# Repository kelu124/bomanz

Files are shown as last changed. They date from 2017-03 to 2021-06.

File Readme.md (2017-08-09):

# Module: A high speed ADC for the RaspberryPi

The board in red:

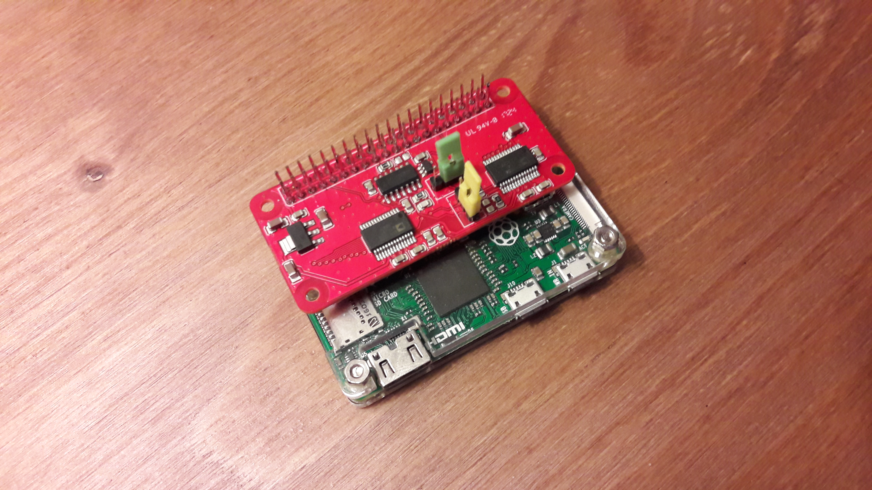
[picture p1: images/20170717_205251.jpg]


## Description

### What is it supposed to do?

I've always needed a small upgrade to the existing raspberry ADC extensions, would love something in the 20-Msps range. Let's see if one can do it! Never tried smd, and thinking of using both smd and dip.. interesting learning curve ahead.

I've tried 3 different versions, increasing in complexity

* An older version using a [CA3306](/CA3306E/) can be found as well: going around 10Msps, 6 bits. DIP based components.
* A possibly [fast version of a 8 bit AD08200 ADC](/ADC08200/) is available, going up to 12Msps. 
* The latest [24Msps pHAT](/AD9200v2/)

### Image of these HATs

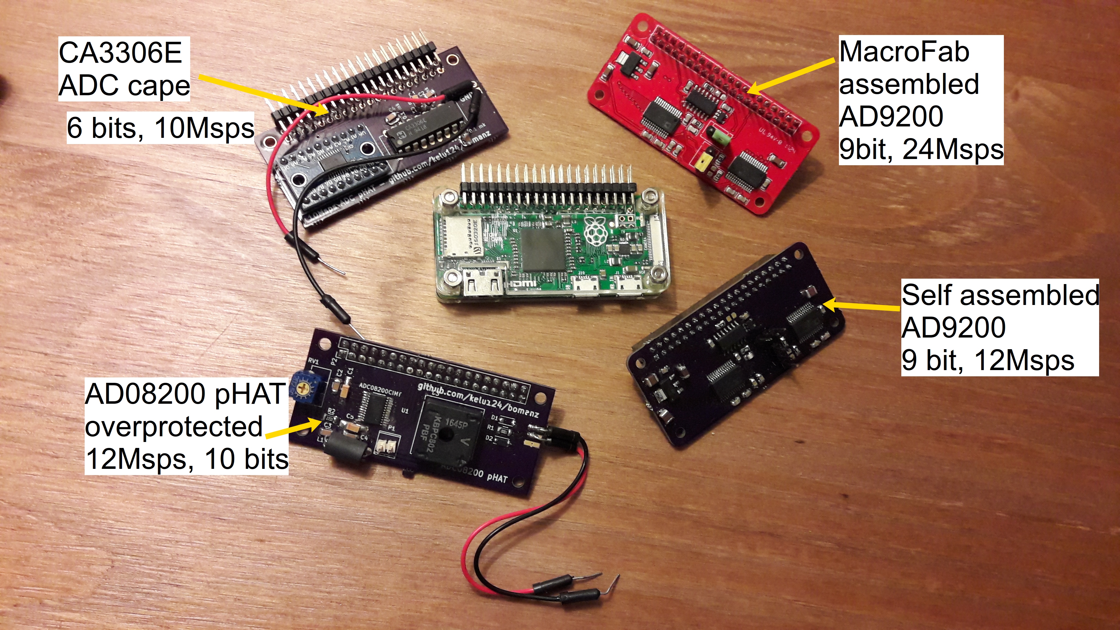
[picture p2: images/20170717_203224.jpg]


## Some results

### 24 Msps with the latest version

Details and FFT of a signal at 1.9MHz

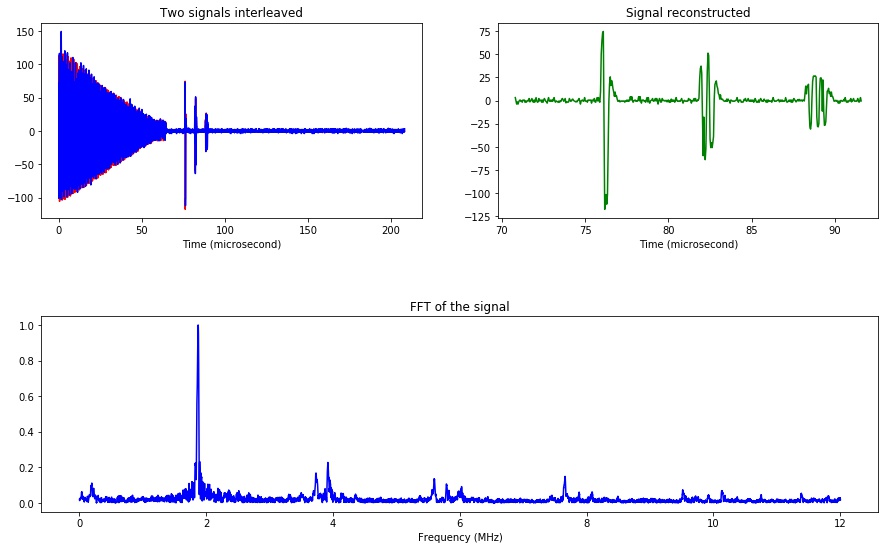
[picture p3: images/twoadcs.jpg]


### 11 Msps with the previous

FFT of a signal at 1.9MHz

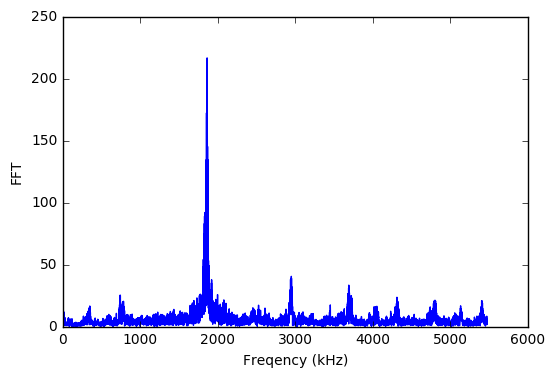
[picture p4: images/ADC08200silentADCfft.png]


### Testing a 1MHz signal with the CA3306

Imaging a 1MHz sine:

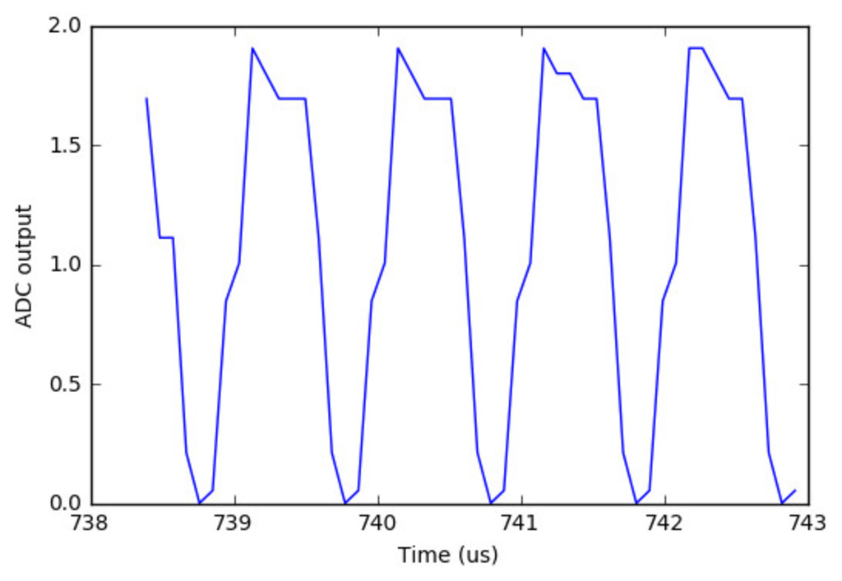
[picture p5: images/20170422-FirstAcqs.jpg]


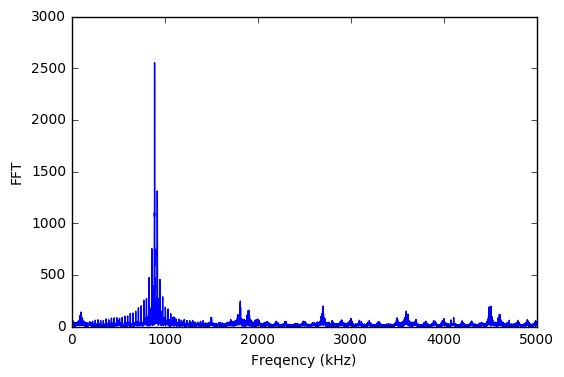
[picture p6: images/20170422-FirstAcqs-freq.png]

 
## License

### Bomanz 

The [echOmods project](https://github.com/kelu124/echomods) and its prototypes (so Bomanz) are open hardware, and working with open-hardware components.

Licensed under TAPR Open Hardware License (www.tapr.org/OHL)

Copyright Kelu124 (kelu124@gmail.com ) 2015-2018

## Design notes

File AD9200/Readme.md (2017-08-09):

# Module: Elmo pHAT [](@description Main doc source for high speed Pi DAQ)



## Name

[`MDL-DAQ_AD9200`]()

## Title

Using a dual ADC raspberry extension for 20Msps+ DAQ

## Description

* High speed ADC pHAT
* version: V1.3
* date: 10/06/2017
* cost:45$
* sourcing:OSHPark, MAcroFab
* technology: SMD, AD9200
* language: n/a
* author: Kelu124

## IOs

### Inputs

* `ITF-1_GND`
* `ITF-2_VDD_5V`
* `ITF-19_3.3V`
* `ITF-12_RPIn`

### Outputs

* `Signal Digitalized`

## Key Components

* `AD9200`

## Information

### What is it supposed to do?

The aim of this module is to achieve 10Msps, ideally 20Msps, at 9bits or more. Inspired from the [Bomanz]() project as well, which tried several high-speed ADCs setup for Raspberry Pi.

### How does it work: block diagram

Block schema

* `Raw Signal`->`ITF-12_RPIn`->`ADC`->`Buffer`->`Pi`->`Signal Digitalized`
* `ITF-4_RawSig`->`ITF-12_RPIn`
* `ITF-11_OffSig`->`ITF-12_RPIn`
* `ITF-3_ENV`->`ITF-12_RPIn`

## About the module

### Pros

* High speed, 9 bit ADCs!

### Cons

* SMDs is tough to assemble?

## Constraint and limits

* Still being debugged

### Discussions

#### Problem and solution

__Problem__ was that the Pi0 or PiW, with the current kernel module, can't run faster than around 10 to 12 Msps. Clock can be faster, but the _memcpy_ limits the transfer to memory. Soooo.. what can we do? As a reminder, I wanted at least a 10Msps 10bit ADC.

__Solution__ Why not interleaving two ADCs, with clocks in opposite phase? Hum that means 2 times 10 bits, and I had only 18 pins left once the Ultrasound SDK board connected. That means.. quite obviously, 2 times 9 bits.

So now I can run at twice the speed of the transfer, so a bit over 20Msps, over this time 9 bits. Or by oversampling, that could be 10Msps at 10 bits. __With more flexibility__ !

Win.

At least for the moment, now I need to order the PCBs and some components.

-> BOM is around 30$ components, 5$ OSHPark PCB.. that's quite neat.

#### First acquisitions:

See the [jupyter notebook](/elmo/data/20170609-NewADC-v3.ipynb):

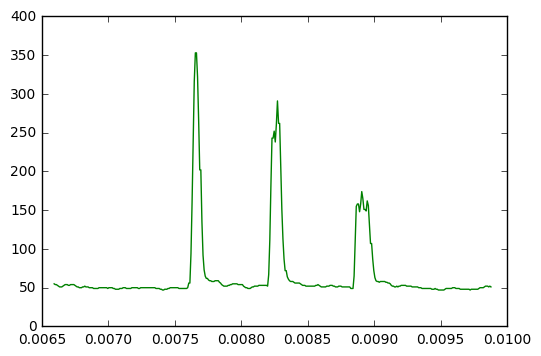
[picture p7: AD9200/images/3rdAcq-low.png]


Issues: bugs in connected ADC pins + no offset really

#### What does it look like ?

__Top in 3D__

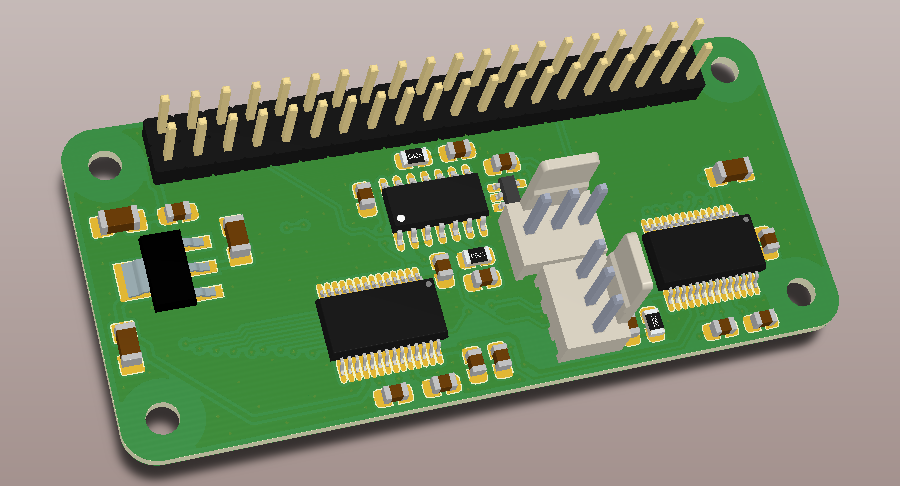
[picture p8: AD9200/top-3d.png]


__Bottom in 3D__

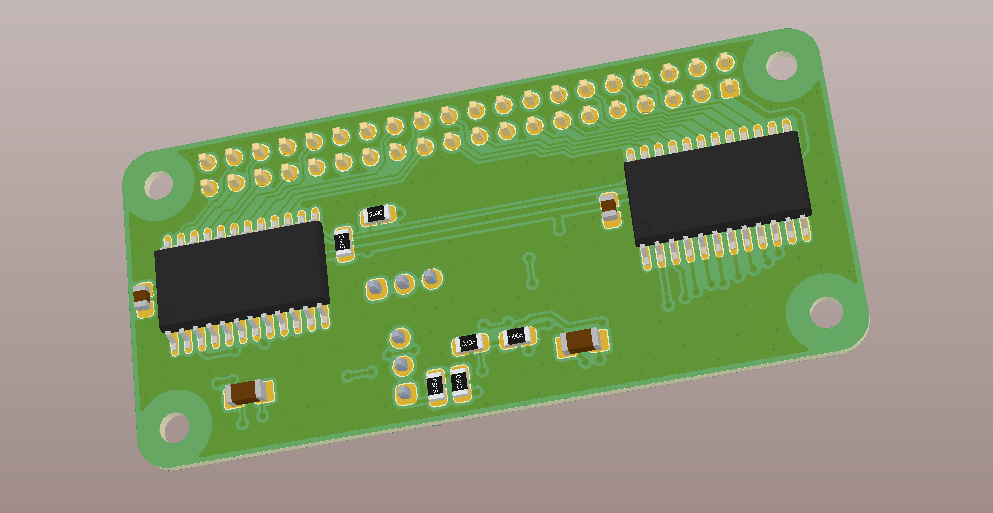
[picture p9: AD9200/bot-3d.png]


### TODO

* Lots
### DONE

* Getting a board an soldering some ADCs

### People

* @ivan for his help on altium

## License

### RetroATL3 

The [echOmods project](https://github.com/kelu124/echomods) and its prototypes (amongst which we find the [ADC pHAT](/elmo/) module) are open hardware, and working with open-hardware components.

Licensed under TAPR Open Hardware License (www.tapr.org/OHL)

Copyright Kelu124 (kelu124@gmail.com ) 2015-2018

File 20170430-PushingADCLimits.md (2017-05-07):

# 20170430 - ADC

## Objectives

1. Testing the ADC08200
2. Offseting the signal
3. Processing data and FFT'ing
4. Checking the power use of the modules at large
5. Next steps

## 1. Testing the ADC08200

Just testing if we can get the noise if we listen to the Ground

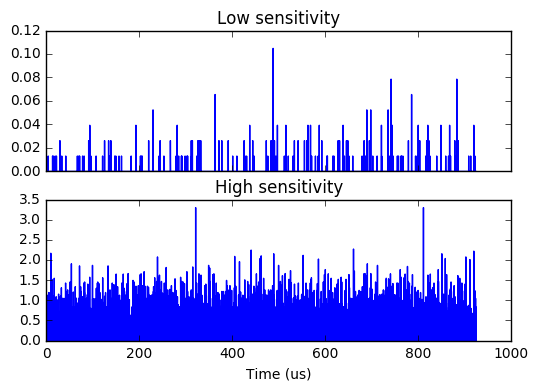
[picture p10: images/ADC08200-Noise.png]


and [getting some info/data](/ADC08200/20170430-ADC08200-FirstAcqs.ipynb)

## 2. Offsetting

The idea is to shift the signal from baseline to an average of 3.3/2V 

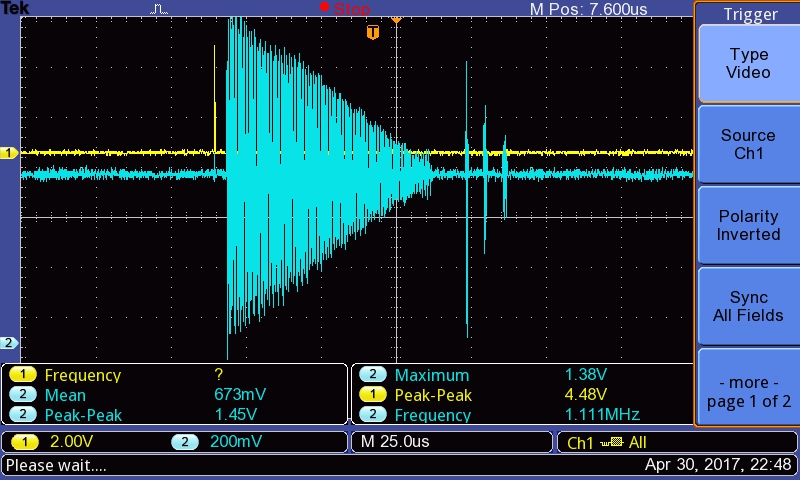
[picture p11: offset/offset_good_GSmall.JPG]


Here, it's a bit bad.

Using a __OP37G__.

## 3. Processing the data

### [First acquisitions with the ADC08200](/ADC08200/20170430-ADC08200-FirstAcqs.ipynb)

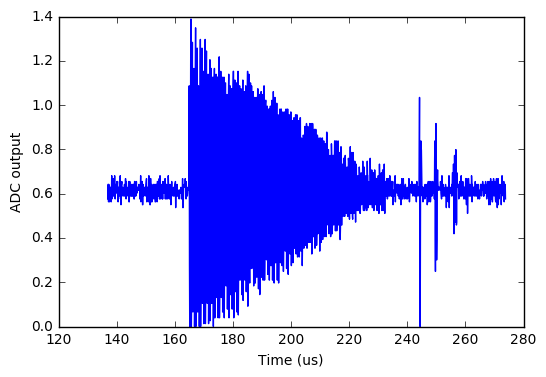
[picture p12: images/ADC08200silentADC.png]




### It should be looking like that:



### And when FFT is applied

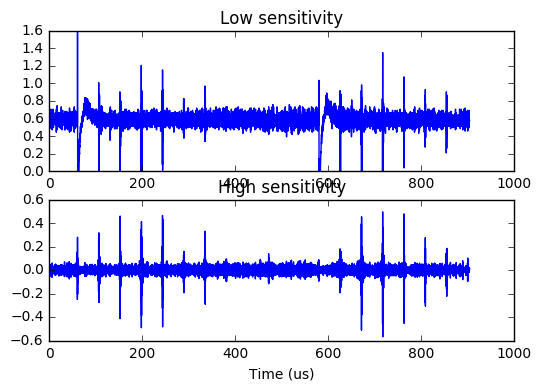
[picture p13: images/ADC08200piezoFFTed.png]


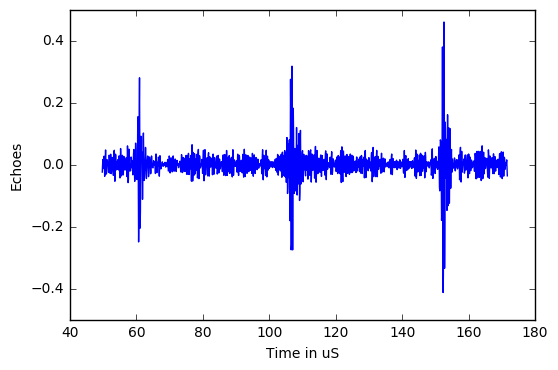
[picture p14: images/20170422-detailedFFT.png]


## 4. Checking the power use

### First stats

That's 5.1V and ...
* 273 mA with OneEye, Tobo, Goblin, Croaker, Oled
* 290 mA with OneEye, Tobo, Goblin, Croaker, Oled and the [offset module](/offset/)
* 390 mA with all of this + the raspberry

### Using with the raspberry powered outside

A simple piezo plugged onto the pulser

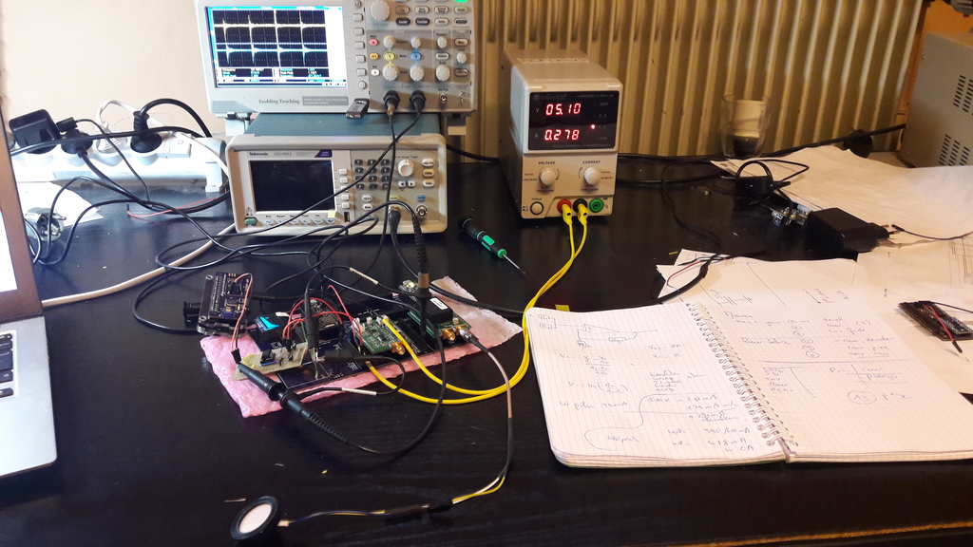
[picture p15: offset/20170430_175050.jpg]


* __Using: 5.1V et 278mA__

### Using a raspberry on the board

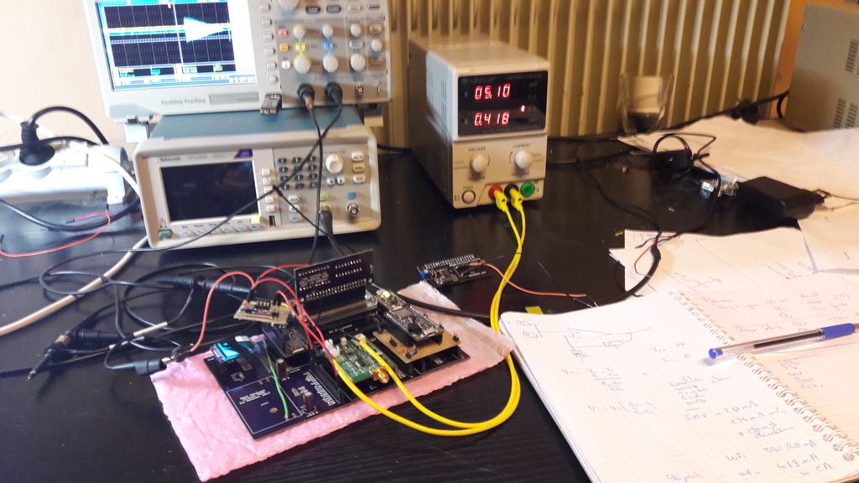
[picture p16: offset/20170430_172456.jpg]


* __Using: 5.1V et 418mA__

## 5. Next steps & challenges

__Tomorrow__
* [ ] Update the [motherboard](https://github.com/kelu124/echomods/blob/master/doj/brief_v2.md)
* [ ] Test noise on the sequence for the emulator 
* [x] Play with the VRef - [done, and not so interesting (see Notebook)](/ADC08200/20170501-TestingVref.ipynb)
* [x] Test the enveloppe detection - done, with [Hilbert and BiVi transform](/ADC08200/20170430-ADC08200-FirstAcqs.ipynb)

__Later on__
* [CANCELLED] !! Do a small PCB for the offsetter
    * Offset by 3.3V/2
    * Gain between 0.5 and 2 with a settable potentiometer 
* Check the control of the pulser by the RPi: control sequence through the ADC module
* Check if the speed of ADC acquisition can be higher

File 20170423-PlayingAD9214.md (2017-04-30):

# Alternatives

## AD9214

Drivé upstream : http://www.analog.com/media/en/technical-documentation/data-sheets/AD8475.pdf

## PRUDAQ - AD9201

The AD9201 is a complete dual channel, 20 MSPS, 10-bit
CMOS ADC used in the [PRUDAQ](http://www.cnx-software.com/2016/07/21/google-research-prudaq-is-a-40msps-adc-data-acquisition-daq-cape-for-beaglebone-black-green/)

- AD9201: 11€
- [Datasheet](/pdf/AD9201.pdf): 
 
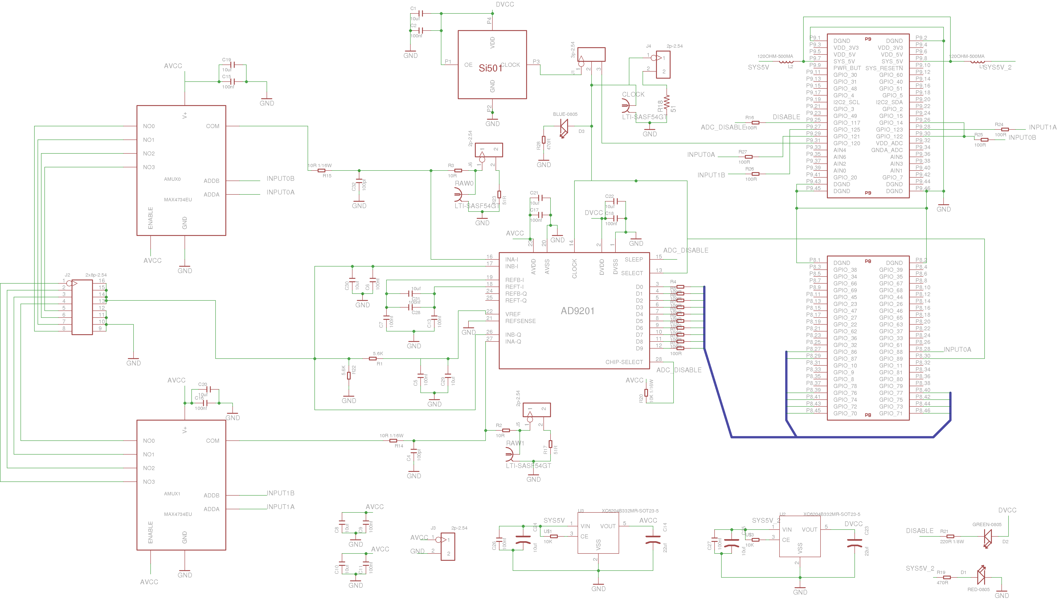
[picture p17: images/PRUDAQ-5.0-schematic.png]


## Other ?

* AD9215 for 10 bit 10-Bit, 65/80/105 MSPS
    * http://www.analog.com/en/products/analog-to-digital-converters/ad9215.html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

* AD9236 for 12 bit resolution ( http://www.analog.com/media/en/technical-documentation/data-sheets/AD9236.pdf )
* AD9245 for 14 bit resolution

* [ADC08200 for bomanz](pdf/adc08200.pdf) ... 8 bit output (1/256) 24-Lead TSSOP

## Input : low pass filter (40MHz)

* Capping

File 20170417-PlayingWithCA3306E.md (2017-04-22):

# Log file

## Intro, references, ...

Original here: https://github.com/themagpimag/magpi-issue24/tree/master/PiScope .. and with [the copy of the txt](/CA3306E/code/piscope.txt).

.. even the original ... http://paul.sullivan.za.org/raspberry-pi-oscilloscope/EE-October-1991/

See http://www.instructables.com/id/PiScope-Raspberry-Pi-based-Oscilloscope/ - inspiration for the whole project. Heart of the build:
* CA3306 (6 bit parallel A/D converter IC) -- see [datasheet](/pdf/CA3306.pdf)
* TXB0108 (logic level converter IC) 

Note to self: [Bomanz on OSHPark](https://blog.oshpark.com/2017/04/15/high-speed-adc-phat-for-raspberry-pi/), yeay!!

### Biblio

- [x] PiScope on [MagPi24](https://github.com/themagpimag/magpi-issue24/tree/master/PiScope)
- [ ] Article from [Paul Sullivan](http://paul.sullivan.za.org/raspberry-pi-oscilloscope/)
- [x] Article from [EE Oct 1991](http://paul.sullivan.za.org/raspberry-pi-oscilloscope/EE-October-1991/)
- [ ] [Instructable ref doc](http://www.instructables.com/id/PiScope-Raspberry-Pi-based-Oscilloscope/ )
- [ ] [Info on DigiBird](https://digibird1.wordpress.com/raspberry-pi-as-an-oscilloscope-10-msps/): comments on noise from the GPIOs read
- [ ] [Explainations on the kernel and macros](http://www.pieter-jan.com/node/15)
- [ ] [Better input management](http://bobdavis321.blogspot.fr/2013/06/arduino-powered-3-million-samples-per.html)
- [ ] [ARduino clocking](http://www.nutsvolts.com/magazine/article/March2014_Davis	)

## 

### Preparing the RPi

See https://www.raspberrypi.org/documentation/remote-access/ssh/passwordless.md for direct ssh

* Recommend activating Wifi, SSH, VNC beforehand
* note to self: __don't use rpi-update__ before.

### Cleaning the SD card

See this: http://raspi.tv/2016/how-to-free-up-some-space-on-your-raspbian-sd-card-remove-wolfram-libreoffice

```
sudo apt-get purge wolfram-engine wolfram-engine scratch minecraft-pi sonic-pi dillo gpicview penguinspuzzle oracle-java8-jdk openjdk-7-jre oracle-java7-jdk openjdk-8-jre chromium-browser libreoffice*
sudo apt-get remove 
sudo apt-get clean
sudo apt-get autoremove
```

If that's not enough, you can check the remaining packages by size:

```
dpkg-query -Wf '${Installed-Size}\t${Package}\n' | sort -nr | more
```

### Installing

Following the steps:

* Run the [prepareModules.sh script](/CA3306E/code/prepareModules.sh)
* Prepare the module with [ca3306.c](/CA3306E/code/ca3306.c) and the corresponding [Makefile](/CA3306E/code/Makefile) ( `ca3306-drv.c` had a couple of bugs left ) 
* Compile with:

```
sudo make
```

One can obtain details on the module via:

```
modinfo ca3306.ko
```

```
sudo insmod ./ca3306.ko
```

Check with a dmesg where the Major of the chardev with a `dmesg`. Initial source was 248, in my case 243.. check yours =)

```
sudo mknod /dev/chardev c 243 0
```

The first compilation takes a while...

### Testing 

* Test with the [getSample.cpp](/CA3306E/code/getSample.cpp)

```
g++ -o getSample getSample.cpp
./getSample > [data.txt](/CA3306E/data/1MHz.data)
```

And finally we get, for an image of a 0-2V sine at 1MHz:

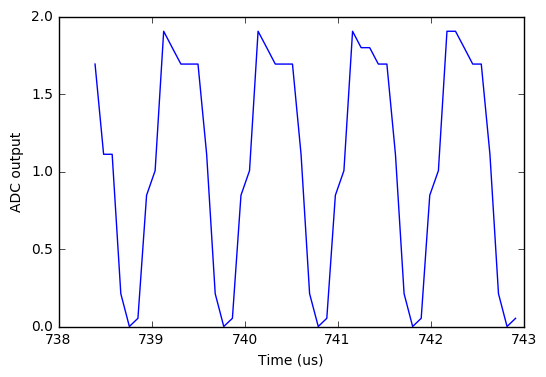
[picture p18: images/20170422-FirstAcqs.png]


Not perfect, can be better, but at least we get something that goes fast =)

### More fun ?

* See the datasheet to increase the sampling frequency with a second ADC
* See how to increase by one bit

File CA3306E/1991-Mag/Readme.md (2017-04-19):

## EE-October-1991

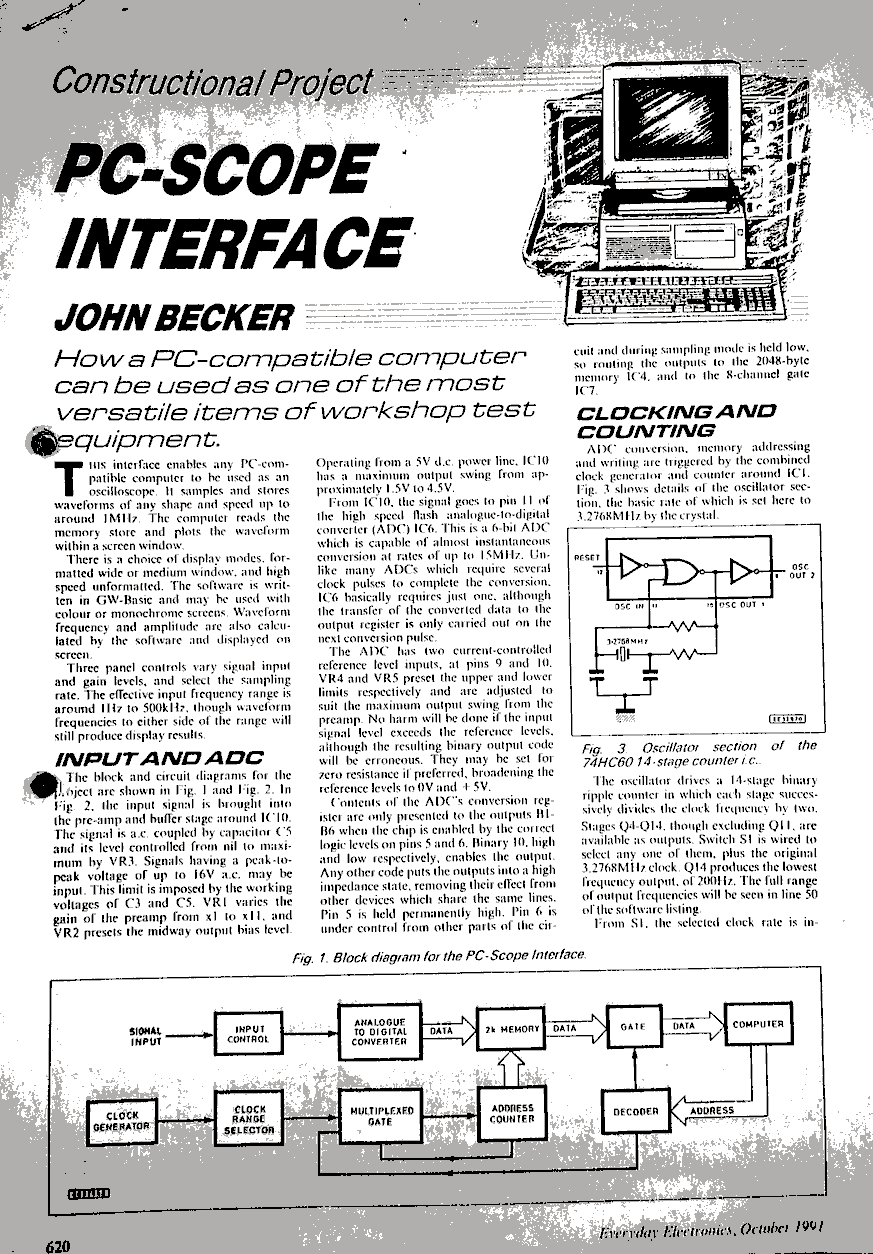
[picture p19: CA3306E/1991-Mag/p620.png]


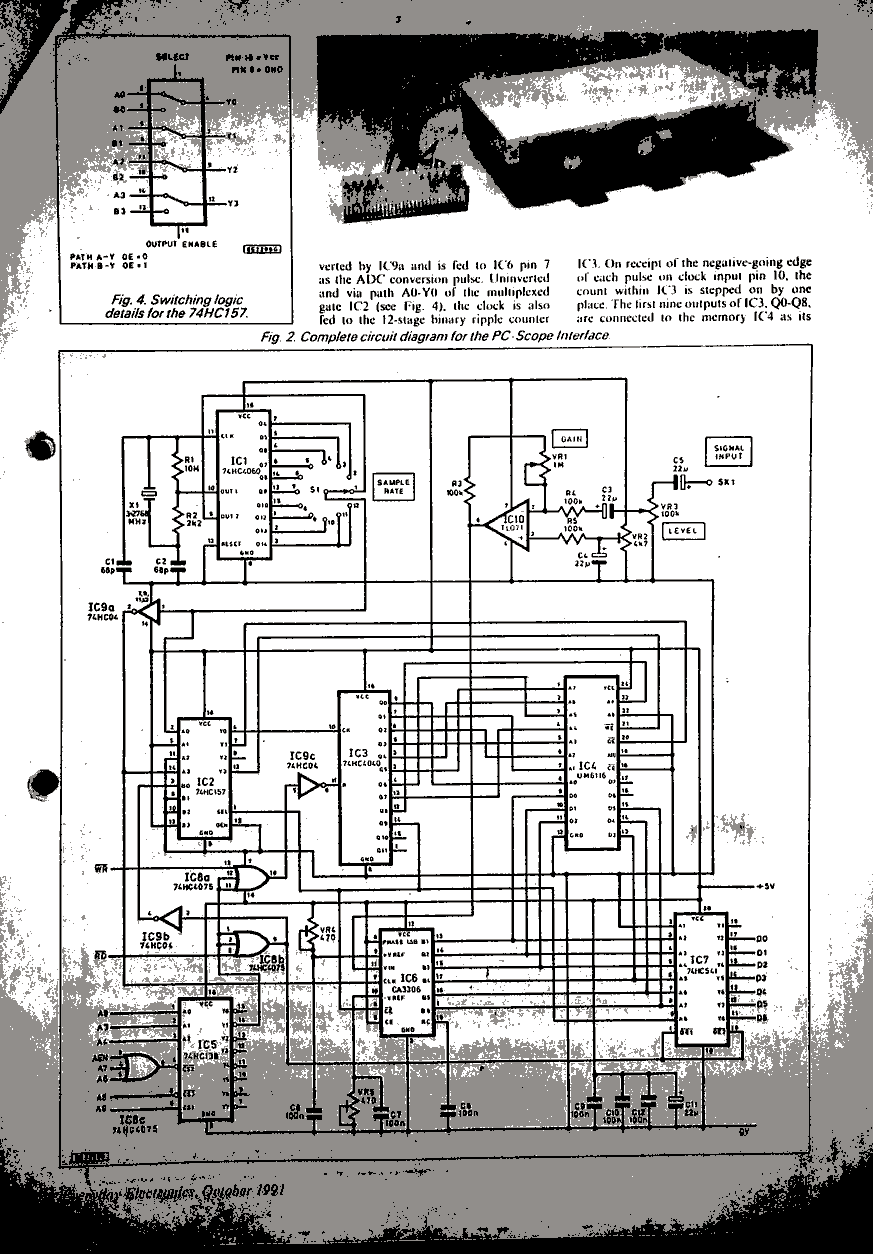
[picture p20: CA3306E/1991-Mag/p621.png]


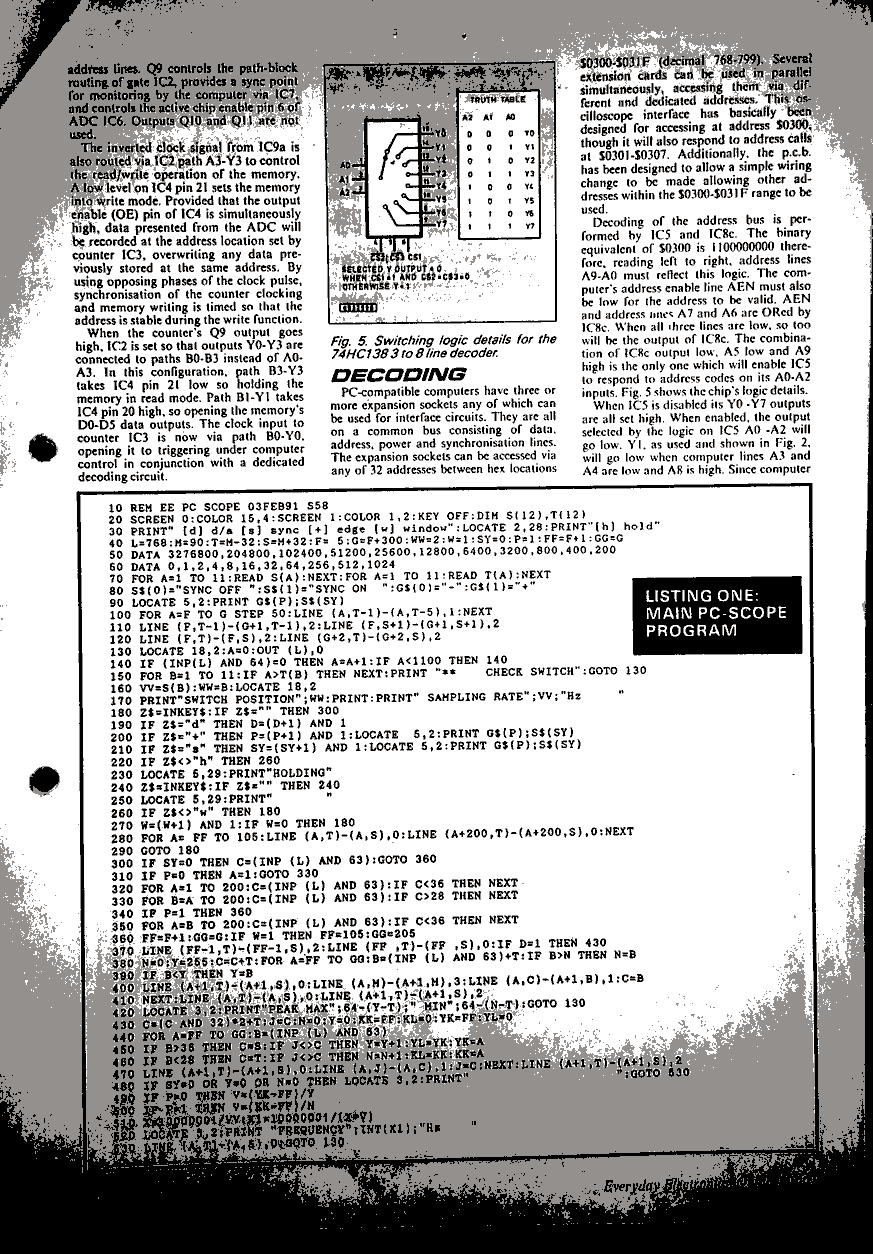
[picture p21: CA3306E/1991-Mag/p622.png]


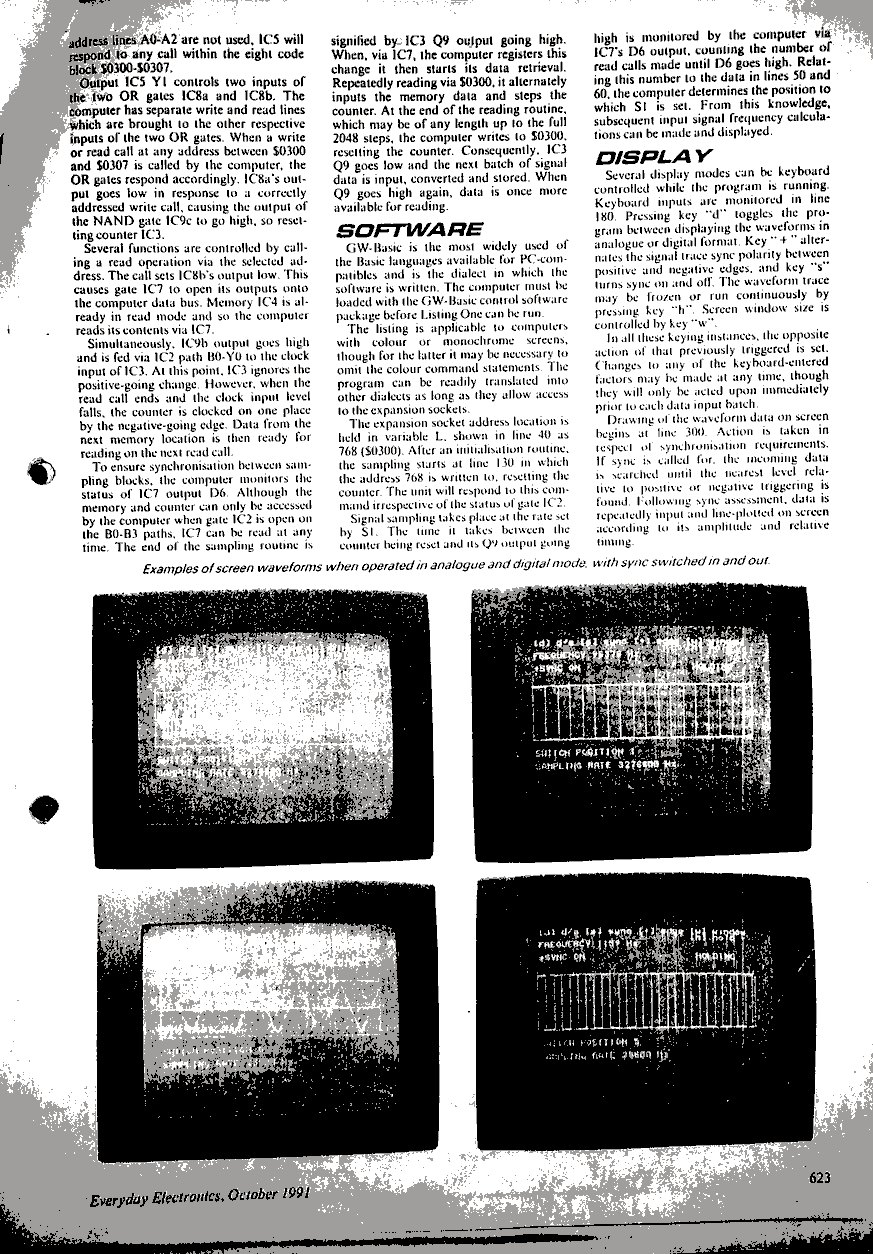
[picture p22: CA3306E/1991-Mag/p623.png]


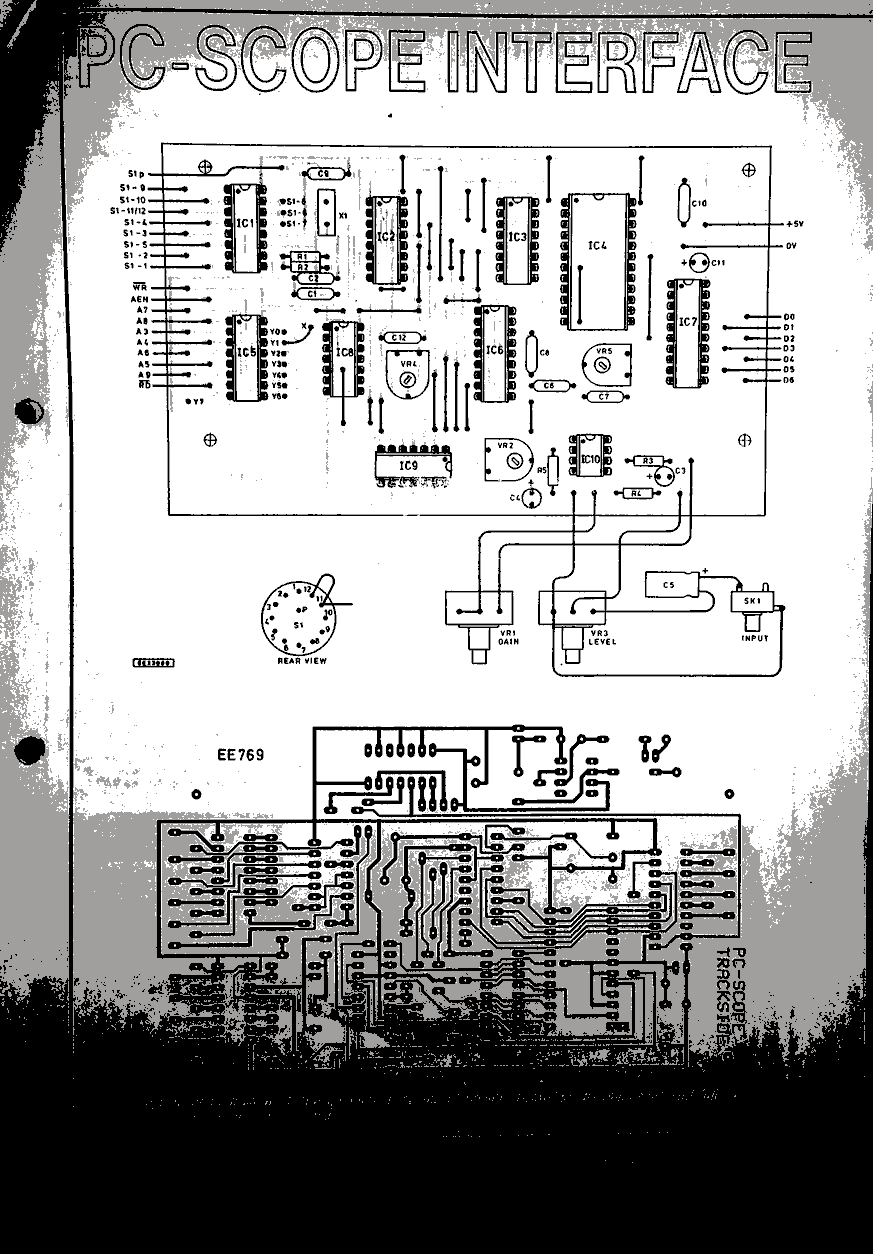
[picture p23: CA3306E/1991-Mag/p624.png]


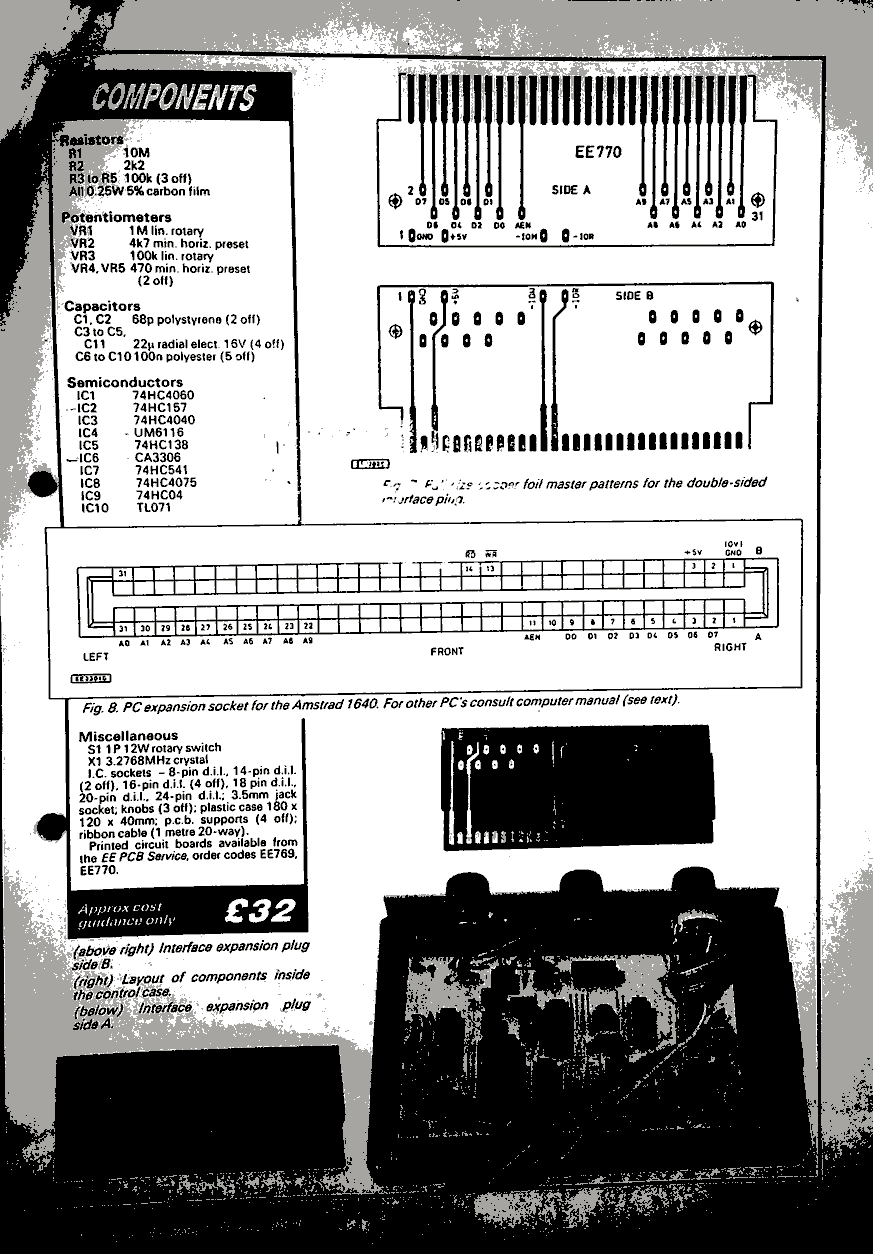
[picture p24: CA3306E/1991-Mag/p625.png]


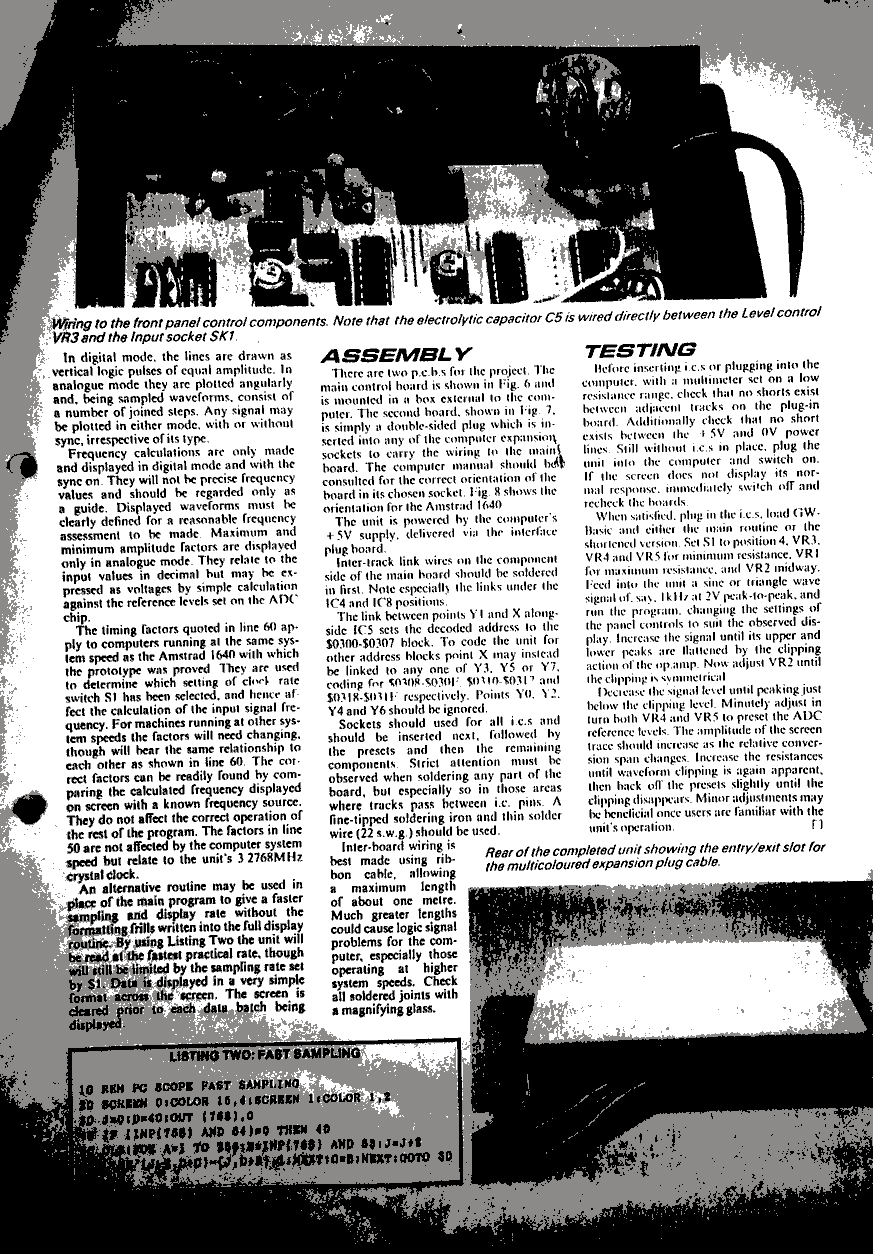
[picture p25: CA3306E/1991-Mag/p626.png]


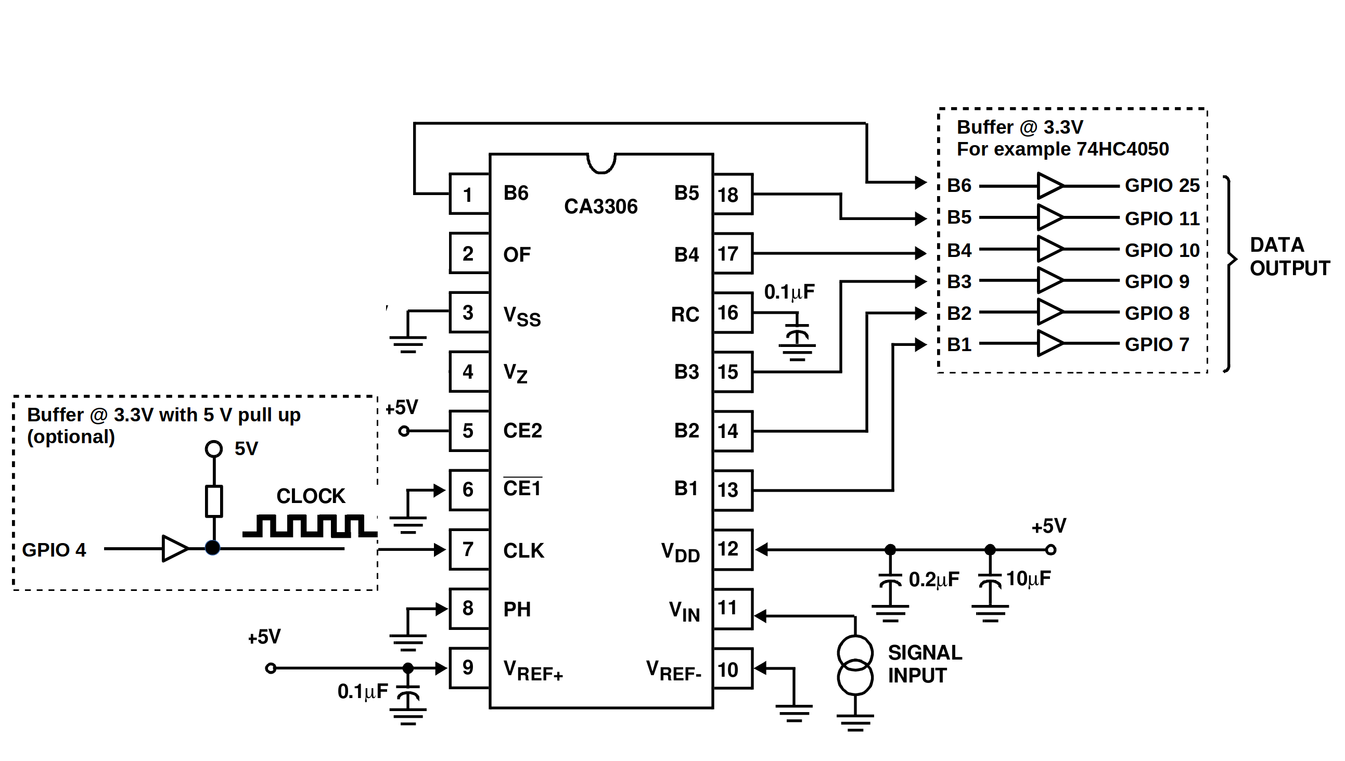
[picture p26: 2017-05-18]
images/drawing.png

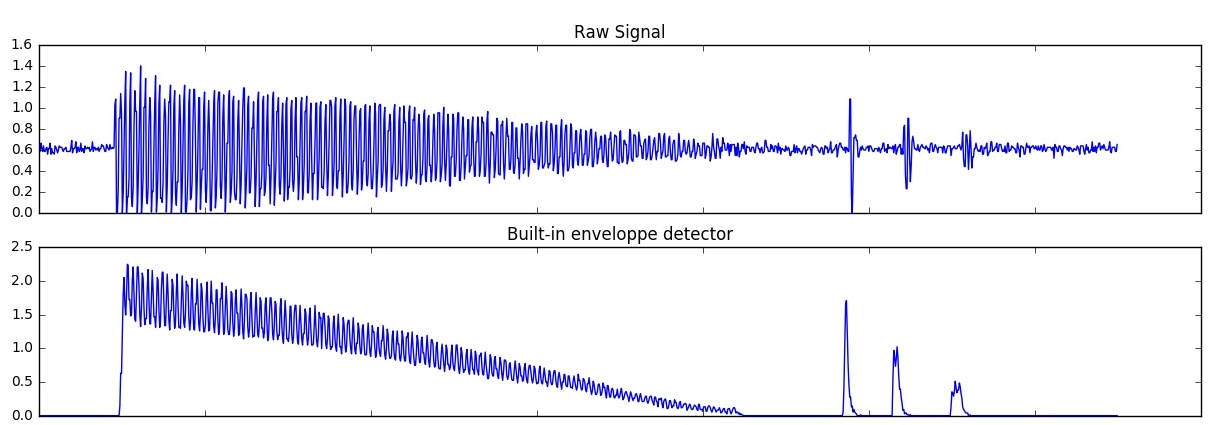
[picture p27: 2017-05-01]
images/SilentSigs.jpg

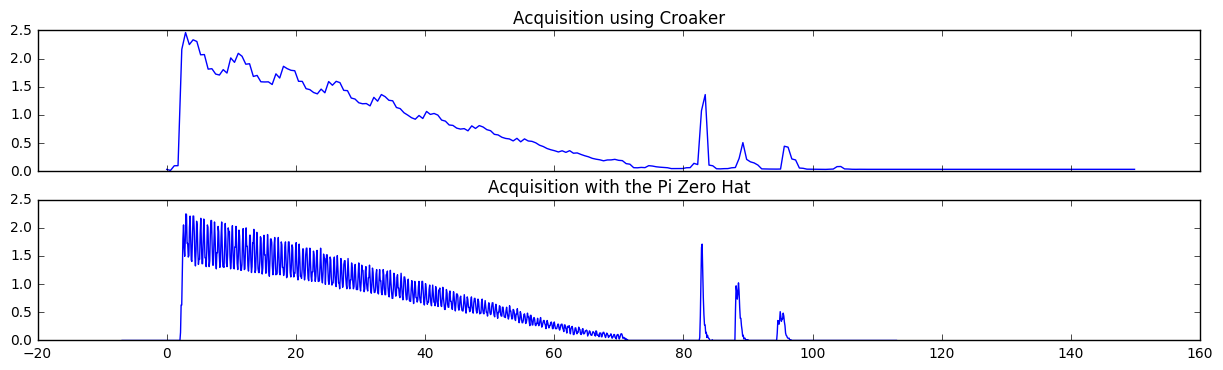
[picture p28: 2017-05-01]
images/BomanzVSCroaker.png

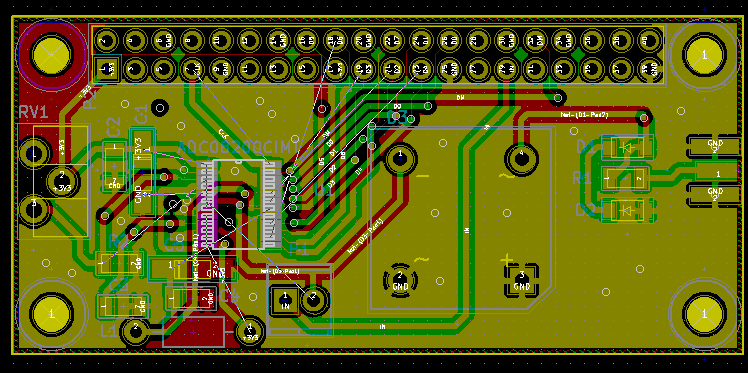
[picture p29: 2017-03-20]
images/bomanz_pcb.png

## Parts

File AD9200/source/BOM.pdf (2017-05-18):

Лист1

Страница 1

Comment | Description | Designator | Footprint | Quantity
100p | Capacitor | C1 | 0805RC | 1
10u | Capacitor | C3, C5, C6, C11, C15, C20 | 1206RC | 6
0.1u | Capacitor | C4, C7, C8, C9, C10, C12, C13, C16, C17, C19, C21, C22, C23 | 0805RC | 13
Header 20X2 | Header, 40-Pin | P1 | PLD-40 | 1
Header 3 | WF-3 etc | P2, P3 | WF-3 | 2
100 | Resistor | R1 | 0805R | 1
51 | Resistor | R2 | 0805R | 1
0 | Resistor | R4 | 0805R | 1
1k | Resistor 1% | R5, R6, R7, R8 | 0805R | 4
150 | Resistor 1% | R9, R10 | 0805R | 2
74LVC14AD | | U1 | M14A_N | 1
SN74LVC1G02DBV | | U2 | SOT-23-5L | 1
SN74LVC841ADW | 10-Bit Bus-Interface D-Type Latch with 3-State Outputs | U3, U5 | DW024_N | 2
AD9200AR | Single 10-bit ADC Parallel 20MSPS | U4, U6 | RS-28_N | 2
LD1117S33TR | Fixed Low Drop Positive Voltage Regulator, 3.3V, 4-Pin SOT-223, Tape and Reel | U7 | SOT223-4N | 1
| Hex Schmitt-Trigger Inverter, 14-Pin SOIC, Commercial Grade

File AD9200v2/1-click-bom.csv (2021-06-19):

References | Qty | Description | Manufacturer | MPN | Manufacturer | MPN | Manufacturer | MPN | Manufacturer | MPN | LCSC | Digikey | Mouser | RS | Newark | Farnell
C1 | 1 | Capacitor 100p 0805 | AVX | 08051A101J4T4A | KEMET | C0805C101J5GACTU | Samsung | CL21C101JBANNNC |  |  | C1790 | 399-1122-6-ND | 80C0805C101J5G | 2644292 |  | 1414656
C3, C5, C6, C11, C15, C20 | 6 | Capacitor 10u 1206 | AVX | TAJA106K016RNJ | Samsung | CL31A106KAHNNNE |  |  |  |  | C7171 | 1276-1075-6-ND | 581TAJA106K016R | 1360124 |  | 1432339
C4, C7, C8, C9, C10, C12, C13, C16, C17, C19, C21, C22, C23 | 13 | Capacitor 0.1u 0805 | Yageo | CC0805KRX7R9BB104 | Murata | GRM21BR71H104KA01L |  |  |  |  | C77082 | 311-1140-6-ND | 603CC805KRX7R9BB104 | 6698842 |  | 3019949
C18 | 1 | Capacitor 10n 0805 | AVX | 08051C103KAT2A | KEMET | C0805C103J5GACTU |  |  |  |  | C188188 | 478-1358-6-ND | 58108051C103K | 8029914 |  | 1535573
P2 | 1 | 3-pin general header PLS-3
P3 | 1 | 2-pin general header SCSL-2
P4 | 1 | Header, 3-Pin, Dual row Header 3X2 PBD-6
R1 | 1 | Resistor 100 0805 | Vishay | CRCW0805100RFKEA | Panasonic | ERJ-6ENF1000V | Yageo | RC0805FR-07100RL |  |  | C193990 | 311-100CRCT-ND | 603RC0805FR07100RL | 6790807 |  | 2459312
R2 | 1 | Resistor 51 0805 | Bourns | CR0805-JW-510ELF | Vishay | CRCW080551R0FKEA | TE Connectivity | CRG0805F51R | Viking Tech | CR-05FL7---51R | C416110 | A126374CT-ND | 652CR0805JW510ELF | 6791538P |  | 1469944
R4 | 1 | Resistor 0 0805 | Vishay | CRCW08050000Z0EA | Panasonic | ERJ-6GEY0R00V | Yageo | RC0805JR-070RL |  |  | C169855 | 311-0.0ARCT-ND | 603RC0805JR070RL | 6790800 |  | 1799478
R5, R6, R7, R8 | 4 | Resistor 1% 1k 0805 | Vishay | CRCW08051K00FKEA | Panasonic | ERJ-6ENF1001V | Yageo | RC0805FR-071KL |  |  | C79496 | 311-1.00KCRCT-ND | 603RC0805FR071KL | 6790982 |  | 2148706
R9, R10 | 2 | Resistor 1% 150 0805 | Bourns | CR0805-FX-1500ELF | Vishay | CRCW0805150RFKEAHP |  |  |  |  |  | CR0805-FX-1500ELFDKR-ND | 652CR0805FX1500ELF | 8123394 |  | 2908392
U1 | 1 | Hex Schmitt-Trigger Inverter, 14-Pin SOIC, Commercial Grade 74LVC14AD M14A_N | Rochester Electronics | 74LVC14AD |  | 74LVC14AD
U2 | 1 | SN74LVC1G02DBV SOT-23-5L | Texas Instruments | SN74LVC1G02DBV |  | SN74LVC1G02DBV
U3, U5 | 2 | 10-Bit Bus-Interface D-Type Latch with 3-State Outputs SN74LVC841ADW DW024_N | Texas Instruments | SN74LVC841ADW |  | SN74LVC841ADW |  |  |  |  |  | 296-8552-5-ND | 595SN74LVC841ADW |  |  | 1741602
U4, U6 | 2 | Single 10-bit ADC Parallel 20MSPS AD9200AR RS-28_N | Analog Devices | AD9200ARS |  |  |  |  |  |  |  |  | 584AD9200ARS
U7 | 1 | Fixed Low Drop Positive Voltage Regulator, 3.3V, 4-Pin SOT-223, Tape and Reel LD1117S33TR SOT223-4N | STMicroelectronics | LD1117S33TR |  | LD1117S33TR |  |  |  |  | C86781 | 497-1242-1-ND | 511LD1117S33 | 7140697 |  | 2393623

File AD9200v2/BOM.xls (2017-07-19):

Comment | Description | Designator | Footprint | Quantity
100p | Capacitor | C1 | 0805RC | 1
10u | Capacitor | C3, C5, C6, C11, C15, C20 | 1206RC | 6
0.1u | Capacitor | C4, C7, C8, C9, C10, C12, C13, C16, C17, C19, C21, C22, C23 | 0805RC | 13
10n | Capacitor | C18 | 0805RC | 1
PLS-3 | 3-pin general header | P2 | PLS-3 | 1
Header 2 | 2-pin general header | P3 | SCSL-2 | 1
Header 3X2 | Header, 3-Pin, Dual row | P4 | PBD-6 | 1
100 | Resistor | R1 | 0805R | 1
51 | Resistor | R2 | 0805R | 1
0 | Resistor | R4 | 0805R | 1
1k | Resistor 1% | R5, R6, R7, R8 | 0805R | 4
150 | Resistor 1% | R9, R10 | 0805R | 2
74LVC14AD | Hex Schmitt-Trigger Inverter, 14-Pin SOIC, Commercial Grade | U1 | M14A_N | 1
SN74LVC1G02DBV |  | U2 | SOT-23-5L | 1
SN74LVC841ADW | 10-Bit Bus-Interface D-Type Latch with 3-State Outputs | U3, U5 | DW024_N | 2
AD9200AR | Single 10-bit ADC Parallel 20MSPS | U4, U6 | RS-28_N | 2
LD1117S33TR | Fixed Low Drop Positive Voltage Regulator, 3.3V, 4-Pin SOT-223, Tape and Reel | U7 | SOT223-4N | 1

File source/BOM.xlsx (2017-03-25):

Sr. No. | Designator | Description | Package | Quantity | URL | Part No.
1 | P2 | Pin Header Straight 2x20 Pitch2.54mm | 2x20 DIP 2.54 mm Pitch | 1 | http://www.digikey.com/product-detail/en/ amphenol-fci/10046971-003LF/609-2859-ND/1589877 | 10046971-003LF
2 | U1 | ADC08200 24 Pin | TSSOP | 1 | http://www.digikey.com/product-detail/ en/texas-instruments/ADC08200CIMT-NOPB/ADC08200CIMT-NOPB-ND/482880 (http://www.digikey.com/product-detail/en/texas-instruments/ADC08200CIMT-NOPB/ADC08200CIMT-NOPB-ND/482880) | ADC08200CIMT/NOPB-ND
3 | C1,C5 | Capacitor Tantalum 10uF | 1206 | 2 | http://www.digikey.com/products/ en?keywords=399-3684-2-ND (http://www.digikey.com/products/en?keywords=399-3684-2-ND) | 399-3684-2-ND
4 | C2,C3,C4 | Capacitor 0.1uF | 1206 | 3 | http://www.digikey.com/products /en?keywords=399-1249-2-ND (http://www.digikey.com/products/en?keywords=399-1249-2-ND) | 399-1249-2-ND
5 | D1,D2 | Zener Diode | SOD-123 | 2 | http://www.digikey.com/products /en?keywords=mmsz5221b-fditr-nd (http://www.digikey.com/products/en?keywords=mmsz5221b-fditr-nd) | MMSZ5221B-FDITR-ND
6 | D3 | Diode Bridge rectifier | 4-Square, D-72 (15.7 x15.7) | 1 | http://www.digikey.com/products/ en?keywords=vs-kbpc802pbfgi-nd (http://www.digikey.com/products/en?keywords=vs-kbpc802pbfgi-nd) | VS-KBPC802PBFGI-ND
7 | L1 | Choke | Axial (0.236" Dia x 0.394" L (5.99mm x 10.01mm)) | 1 | http://www.digikey.com/ products/en?keywords=M2204-ND (http://www.digikey.com/products/en?keywords=M2204-ND) | M2204-ND
8 | P1 | Pin Header Straight 1x2 Pitch2.54mm | 1x2 DIP 2.54 mm Pitch | 1 | http://www.digikey.com/products/ en?keywords=sam9523-nd (http://www.digikey.com/products/en?keywords=sam9523-nd) | SAM9523-ND
9 | R2 | Resistor 220 Ohms | 1206 | 1 | http://www.digikey.com/ products/en?keywords=311-220frtr-nd (http://www.digikey.com/products/en?keywords=311-220frtr-nd) | 311-220FRTR-ND
10 | R1 | Ressitor 100 Ohms | 1206 | 1 | http://www.digikey.com/product-detail/ en/yageo/RC1206FR-07100RL/311-100FRTR-ND/728491 (http://www.digikey.com/product-detail/en/yageo/RC1206FR-07100RL/311-100FRTR-ND/728491) | 311-100FRTR-ND
11 | RV1 | Potentiometer | Mounting Hole Square - 0.276" x 0.276" Face x 0.228" L (7.00mm x 7.00mm x 5.80mm) | 1 | http://www.digikey.com/products/ en?keywords=CT6ep202-ND (http://www.digikey.com/products/en?keywords=CT6ep202-ND) | CT6EP202-ND
12 |  | SMA Edge Connector | Board Edge, End Launch | 1 | http://www.digikey.com/ products/en?keywords=ACX1652-ND (http://www.digikey.com/products/en?keywords=ACX1652-ND) | ACX1652-ND

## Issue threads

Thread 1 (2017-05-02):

LTC2321-16

darkcurrent, 2017-05-02:
Hi Ghosh,

[LTC2321-16](http://cds.linear.com/docs/en/datasheet/232116fa.pdf) is excellent ADC _(16 bit, 2Msps Throughput Rate)_ considering its high bit depth, high sampling rate and reasonably low price . Since high bit rate sampling is very essential in many application areas, maybe you can use this ADC IC in your further ADC board projects like Bomanz project.

Regards,

kelu124, 2017-05-16:
Hi @darkcurrent - and thanks for your feedback!
If speed is what you are looking for, the performances of the current pHAT are at around 10Msps, at 8 bit. Would this fit in with your _high bit rate sampling_ requirement? Note that this is possible because the ADC speaks in serial with the raspberry.
If your own target is 2Msps, feel free to try to implement one. The issue then in using the LTC2321-16  is that your communication protocol is at least of 2Msps * 16 bit -> 36MHz clock (actually more, due to overheads), which the raspberry may or may not tolerate.
That being said, the kernel module also allows to slow down the clock, so you may also reach 2Msps using either option (ADC08200 or the CA3306) to acquire your signal.
Hope that helps!

Closed 2017-05-16.

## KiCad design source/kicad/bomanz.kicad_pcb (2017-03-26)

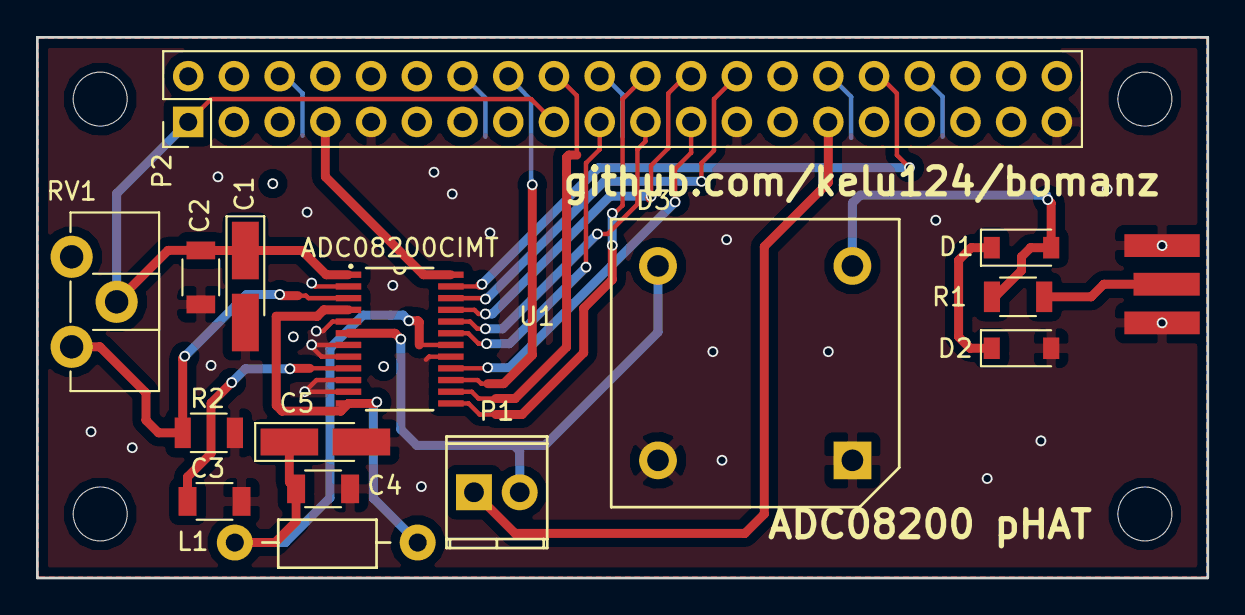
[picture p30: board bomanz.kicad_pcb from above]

Board: 2 copper layers, 65.0 x 30.0 mm, 15 parts (0 on the bottom side), 19 nets.

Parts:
C1, C5: CP_Tantalum_Case-A_EIA-3216-18_Hand
C2, C3, C4: C_1206
D1, D2: D_SOD-123
D3: Diode_Bridge_15.7x15.7
L1: Choke_Horizontal_RM10mm
P1: TerminalBlock_Pheonix_MPT-2.54mm_2pol
P2: Pin_Header_Straight_2x20_Pitch2.54mm
R1, R2: R_1206
RV1: Potentiometer_Trimmer_ACP_CA9h2.5_Vertical_Px2.5mm_Py5.0mm
U1: ADC08200CIMT; ADC08200_PW_24

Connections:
+3V3: C1.1, C2.1, L1.1, P2.1, P2.17, RV1.2, U1.1, U1.4, U1.12
CLK: P2.7, U1.24
D0: P2.26, U1.22
D1: P2.24, U1.21
D2: P2.21, U1.20
D3: P2.19, U1.19
D4: P2.23, U1.16
D5: P2.16, U1.15
D6: P2.18, U1.14
D7: P2.22, U1.13
DM: P2.32, U1.23
GND: C1.2, C2.2, C3.2, C4.2, C5.2, D2.2, D3.2, D3.3, P2.6, P2.9, P2.14, P2.20, P2.25, P2.30, P2.34, P2.39, R2.2, U1.2, U1.5, U1.7, U1.8, U1.10, U1.11, U1.17
IN: P1.1, P2.29
unnamed: C3.1, U1.9
unnamed: C4.1, C5.1, L1.2, U1.18
unnamed: D1.1, D2.1
unnamed: D1.2, D3.4, R1.1
unnamed: D3.1, P1.2, U1.6
unnamed: R2.1, RV1.3, U1.3

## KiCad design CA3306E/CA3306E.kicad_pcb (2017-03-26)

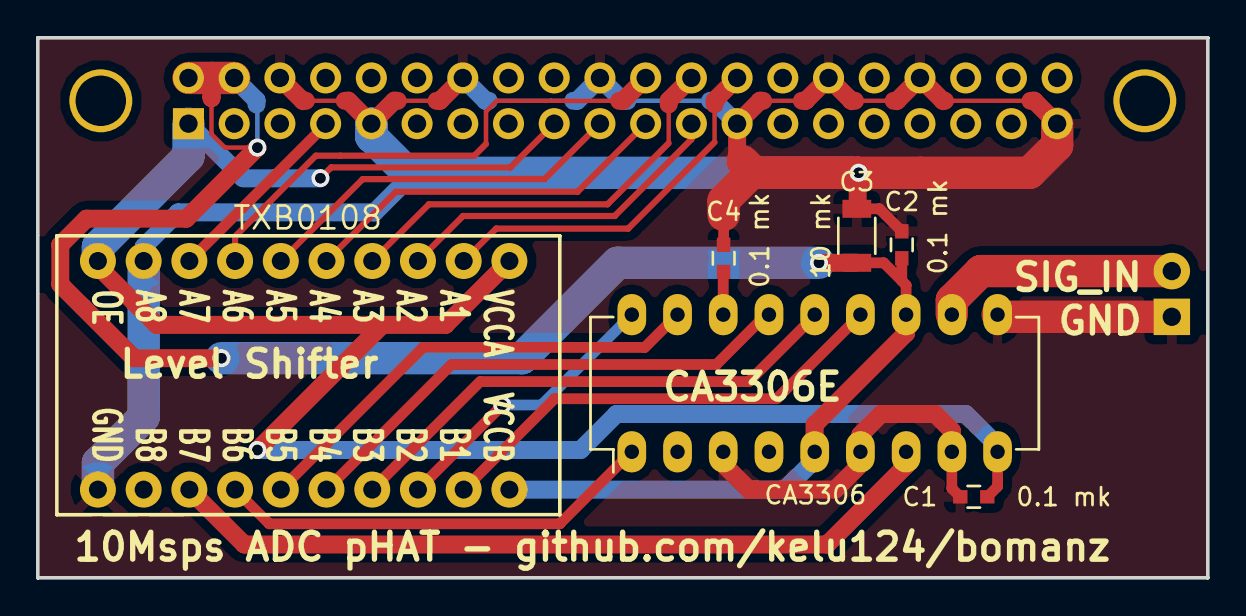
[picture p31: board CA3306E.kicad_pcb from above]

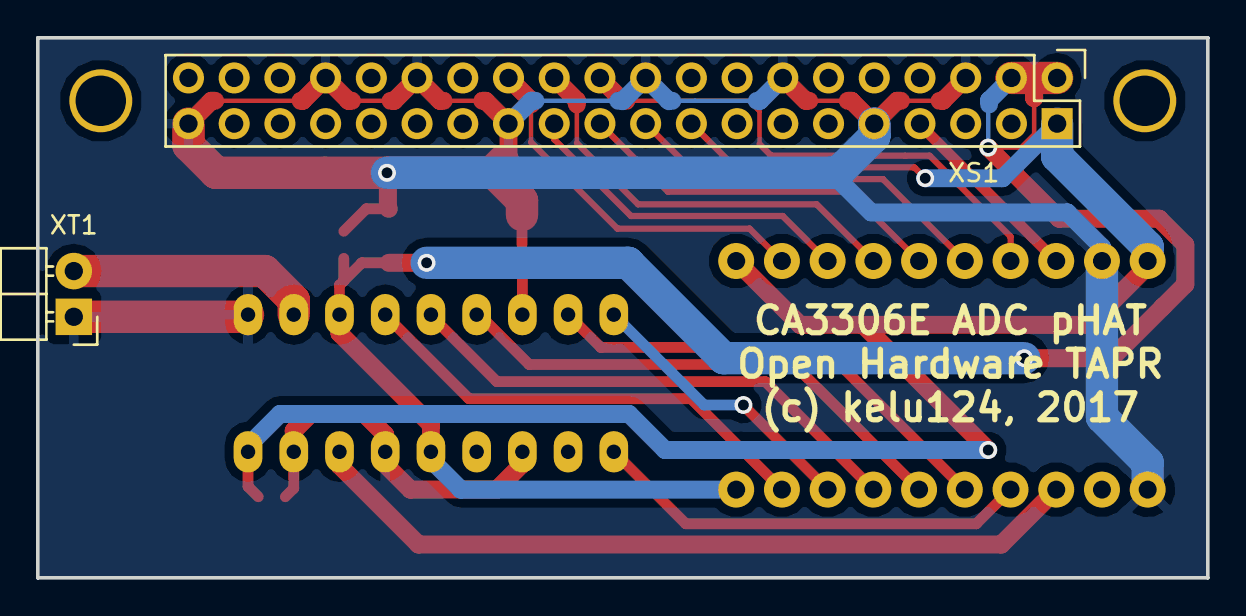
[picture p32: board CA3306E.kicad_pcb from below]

Board: 2 copper layers, 65.0 x 30.0 mm, 8 parts (2 on the bottom side), 19 nets.

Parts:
C1, C2, C4: 0.1 mk; C_0603
C3: 10 mk; C_1206
CA3306: DIP-18_W7.62mm_LongPads
TXB0108: MountingHole_6mm_Pad
XS1: Pin_Header_Straight_2x20
XT1: Pin_Header_Angled_1x02

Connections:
B1: CA3306.13, TXB0108.19
B2: CA3306.14, TXB0108.17
B3: CA3306.15, TXB0108.16
B4: CA3306.17, TXB0108.15
B5: CA3306.18, TXB0108.18
B6: CA3306.1, TXB0108.14
C4_P: C4.1, CA3306.16
CLK: CA3306.7, TXB0108.13
GND: C1.2, C2.2, C3.2, C4.2, CA3306.3, CA3306.6, CA3306.8, CA3306.10, TXB0108.9, TXB0108.11, XS1.6, XS1.9, XS1.14, XS1.20, XS1.25, XS1.30, XS1.34, XS1.39, XT1.1
GPIO4: TXB0108.8, XS1.7
GPIO7: TXB0108.2, XS1.26
GPIO8: TXB0108.4, XS1.24
GPIO9: TXB0108.5, XS1.21
GPIO10: TXB0108.6, XS1.19
GPIO11: TXB0108.3, XS1.23
GPIO25: TXB0108.7, XS1.22
SIG_IN: CA3306.11, XT1.2
VDD_3V3: C1.1, CA3306.9, TXB0108.1, TXB0108.10, XS1.1, XS1.17
VDD_5V: C2.1, C3.1, CA3306.5, CA3306.12, TXB0108.20, XS1.2, XS1.4

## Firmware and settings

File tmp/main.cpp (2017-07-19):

/*
	Developed by Daniel Pelikan 2013,2014
	http://digibird1.wordpress.com/
*/

#include <iostream>
#include <cmath>
#include <fstream>
#include <bitset>

typedef unsigned short    uint16_t;
typedef unsigned int      uint32_t;

const int DataPointsRPi=10000;
//This is the structre we get from the Raspberry pi
struct DataStructRPi{
        uint32_t Buffer[DataPointsRPi];
        uint32_t time;
};
//---------------------------------------------------------------------------------------------------------
int main(){

    //Read the RPi
    struct DataStructRPi dataStruct;
    unsigned char *ScopeBufferStart;
    unsigned char *ScopeBufferStop;
    unsigned char *buf_p;

    buf_p=(unsigned char*)&dataStruct;
    ScopeBufferStart=(unsigned char*)&dataStruct;
    ScopeBufferStop=ScopeBufferStart+sizeof(struct DataStructRPi);

    std::string line;
    std::ifstream myfile ("/dev/chardev");
    if (myfile.is_open())
    {
      while ( std::getline (myfile,line) )
      {
        for(int i=0;i<line.size();i++){
          if(buf_p>ScopeBufferStop) std::cerr<<"buf_p out of range!"<<std::endl;
          *(buf_p)=line[i];
          buf_p++;
        }
      }
      myfile.close();
    }
    else std::cerr << "Unable to open file"<<std::endl;
//---------------------------------------------------------------------------------------------------------
    //convert structure we get from RPi to text output
    double time=dataStruct.time/(double)DataPointsRPi;//time step in ns

    for(int i=0;i<DataPointsRPi;i++){

        int valueADC1=0;//ADC 1
        //move the bits to the right pos
        int tmp = dataStruct.Buffer[i] & (0b11111<<(7));
        valueADC1=tmp>>(7);
        tmp = dataStruct.Buffer[i] & (0b1<<(25));
        valueADC1+=(tmp>>(20));


        int valueADC2=0;//ADC2
        tmp = dataStruct.Buffer[i] & (0b11<<(17));
        valueADC2=tmp>>17;
        tmp=dataStruct.Buffer[i] & (0b111<<(22));
        valueADC2+=(tmp>>20);
        tmp=dataStruct.Buffer[i] & (0b1<<27);
        valueADC2+=(tmp>>22);

        std::cout<<i*time<<"\t"<<valueADC1*(5./63.)<<"\t"<<valueADC2*(5./63.)<<std::endl;
    }
    return 0;
}

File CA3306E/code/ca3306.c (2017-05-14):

/*
*	Developed by Daniel Pelikan 2013,2014
*	http://digibird1.wordpress.com/
*	Reviewed by @kelu124
*/

#include <linux/kernel.h>
#include <linux/module.h>
#include <linux/fs.h>
#include <linux/uaccess.h>
#include <linux/time.h>
#include <linux/io.h>
#include <linux/vmalloc.h>

static int device_open(struct inode *, struct file *);
static int device_release(struct inode *, struct file *);
static ssize_t device_read(struct file *, char *, size_t, loff_t *);
static ssize_t device_write(struct file *, const char *, size_t, loff_t *);

#define SUCCESS 0
/* Dev name */
#define DEVICE_NAME "chardev"
/* Max length of device message */
#define BUF_LEN 80

/* Things for the GPIO Port */

#define BCM2708_PERI_BASE       0x20000000
/* GPIO controller */
#define GPIO_BASE (BCM2708_PERI_BASE + 0x200000)
/* #define BLOCK_SIZE (4*1024) */

#define INP_GPIO(g)   ((*(gpio.addr + ((g) / 10))) &= ~(7 << (((g) % 10) * 3)))
#define OUT_GPIO(g)   ((*(gpio.addr + ((g) / 10))) |=  (1 << (((g) % 10) * 3)))
/* alternative function */
#define SET_GPIO_ALT(g, a) (*(gpio.addr + (((g) / 10))) |= (((a) <= 3 ? (a) + 4 : (a) == 4 ? 3 : 2) << (((g) % 10) * 3)))

/* sets   bits which are 1 ignores bits which are 0 */
#define GPIO_SET  (*(gpio.addr + 7))

/* clears bits which are 1 ignores bits which are 0 */
#define GPIO_CLR  (*(gpio.addr + 10))

#define GPIO_READ(g)  ((*(gpio.addr + 13)) &= (1 << (g)))

/* GPIO Clock */
#define CLOCK_BASE              (BCM2708_PERI_BASE + 0x00101000)
#define GZ_CLK_BUSY BIT(7)


/* How many samples to capture */
#define SAMPLE_SIZE	10000

/* Define GPIO Pins */

/* ADC 1 */
#define BIT0_PIN 7
#define BIT1_PIN 8
#define BIT2_PIN 9
#define BIT3_PIN 10
#define BIT4_PIN 11
#define BIT5_PIN 25

/* ADC 2 */
#define BIT0_PIN2 17
#define BIT1_PIN2 18
#define BIT2_PIN2 22
#define BIT3_PIN2 23
#define BIT4_PIN2 24
#define BIT5_PIN2 27

<<<<<<< HEAD


#define MY_NOP(__N)                 __asm ("nop");    // or sth like "MOV R0,R0"


//---------------------------------------------------------------------------------------------------------

// IO Acces
=======
/* IO Acces */
>>>>>>> f51eee510a5662ddc95f04a4c4bbeacadafa0bc8
struct bcm2835_peripheral {
	unsigned long addr_p;
	int mem_fd;
	void *map;

	volatile unsigned int *addr;
};

static int map_peripheral(struct bcm2835_peripheral *p);
static void unmap_peripheral(struct bcm2835_peripheral *p);
static void readScope(void);

static int Major; /* Major number assigned to our device driver */

/* Is device open?
* Used to prevent multiple access to device
*/
static int Device_Open;
static char msg[BUF_LEN]; /* The msg the device will give when asked */
static char *msg_Ptr;

static unsigned char *buf_p;

static const struct file_operations fops = {
	.read = device_read,
	.write = device_write,
	.open = device_open,
	.release = device_release
};

/*
* We need to assign the addresses of GPIO and the clock to a variable that we
* can find the hardware. A data structure is defined to hold our values we read
* out from the ADC, as well as the time from start of the readout to the end of
* the readout. This time is needed in order to calculate the time step between
* each sample. Additional two pointers are defined for later operations.
*/
static struct bcm2835_peripheral myclock = { CLOCK_BASE };

static struct bcm2835_peripheral gpio = { GPIO_BASE };

struct DataStruct {
	u32 Buffer[SAMPLE_SIZE];
	u32 time;
};

struct DataStruct dataStruct;

static unsigned char *ScopeBufferStart;
static unsigned char *ScopeBufferStop;

/*
* Since we want to manipulate hardware registers we need to map the hardware
* registers into memory. This can be done by two functions, one for the mapping
* and one for the unmapping.
*/
static int map_peripheral(struct bcm2835_peripheral *p)
{
	p->addr = (uint32_t *)ioremap(GPIO_BASE, 41 * 4);
	return 0;
}

static void unmap_peripheral(struct bcm2835_peripheral *p)
{
	iounmap(p->addr); /* unmap the address */
}

/*
* In our case we are only taking 10k samples so not too much time. Before the
* sample taking we take a time stamp. Then we read out 10k times the GPIO
* register and save it in our data structure. The GPIO register is a 32bit
* value so it is made out of 32 ‘1’s and ‘0’s each defining if
* the GPIO port is high (3.3V) or low (GND). After the read out we take
* another time stamp and turn on all interrupts again. The two time
* stamps we took are important since we can calculate how long it took to
* read in the 10k samples. The time difference divided by 10k gives us
* the time between each sample point. In case the sample frequency is too
* high and should be reduced one can add some delay and waste some time
* during each readout step. Here the aim is to achieve the maximal
* performance.
*/
static void readScope(void)
{
	int counter;

<<<<<<< HEAD
	int counter=0;
	int Pon=0;
	int Poff=0;
	//int Fail=0;

	//disable IRQ
	local_irq_disable();
	local_fiq_disable();

	struct timespec ts_start,ts_stop;
	//Start time

        GPIO_SET = 1 << 23;

	while(Pon<10){
MY_NOP(__N);
Pon++;
}
        GPIO_CLR = 1 << 23;

        GPIO_SET = 1 << 24;
	while(Poff<1500){
MY_NOP(__N);
Poff++;
}
        GPIO_CLR = 1 << 24;




	getnstimeofday(&ts_start);
	//take samples
	while(counter<SAMPLE_SIZE){
		dataStruct.Buffer[counter++]= *(gpio.addr + 13); 
	}
=======
	struct timespec ts_start;
	struct timespec ts_stop;

	/* int Fail=0; */
	counter = 0;

	/* disable IRQ */
	local_irq_disable();
	local_fiq_disable();

	/* Start time */
	getnstimeofday(&ts_start);

	/* take samples */
	while (counter < SAMPLE_SIZE)
		dataStruct.Buffer[counter++] = *(gpio.addr + 13);
>>>>>>> f51eee510a5662ddc95f04a4c4bbeacadafa0bc8

	/* Stop time */
	getnstimeofday(&ts_stop);

<<<<<<< HEAD
	//enable IRQ
=======
	/* enable IRQ */
>>>>>>> f51eee510a5662ddc95f04a4c4bbeacadafa0bc8
	local_fiq_enable();
	local_irq_enable();

	/* save the time difference */
	dataStruct.time = timespec_to_ns(&ts_stop) - timespec_to_ns(&ts_start);

	buf_p = &dataStruct;

	ScopeBufferStart = &dataStruct;

	ScopeBufferStop = ScopeBufferStart + sizeof(struct DataStruct);
}
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

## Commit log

2017-03-20 KiCad sources
    [BOM.xlsx, bomanz.kicad_pcb, bomanz.sch]
2017-03-20 Adding gerbers/drill
    [bomanz-B.Adhes.gbr, bomanz-B.Cu.gbr, bomanz-B.Mask.gbr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]
2017-03-25 Add Gerbers CA3306
    [BOM.xlsx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]
2017-03-26 Adding the CA3306E board
    [CA3306E-B.CrtYd.gbr, CA3306E-B.Cu.gbr, CA3306E-B.Fab.gbr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]
2017-04-06 Adding PCBs images
2017-04-12 Adding the mounted boards pics
2017-04-19 Adding previous compiling error
    [ca3306-drv.c]
2017-04-22 First samples of CA3306
2017-04-30 Adding tests with ADC08200
    [10MHz_adc.csv, 10MHz_emul.csv, 10MHz_piezoNoBack.csv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]
2017-05-01 Adding filters on piezo without backing
2017-05-01 Adding VRef tests and enveloppe detection comparison
    [20170501-ADC08_raw.csv, 20170501-ADC08_raw_b.csv, 20170501-ADC08_raw_c.csv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]
2017-05-22 Adding Doj v2
    [pulser.csv]
2017-05-22 Adding berkAltium files
    [ADC_pHAT.PrjPcb, BOM.xls, PCB1.PcbDoc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]
2017-07-19 Adding the 24Msps version of the ADC pHAT
    [ADC_pHAT.PrjPcb, BOM.xls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]
2019-12-30 Make compatible with kitspace.org
    [1-click-bom.csv]

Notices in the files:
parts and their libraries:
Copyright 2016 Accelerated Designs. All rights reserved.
